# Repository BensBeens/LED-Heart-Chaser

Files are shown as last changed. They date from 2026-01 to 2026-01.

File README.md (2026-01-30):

# LED-Heart-Chaser
Little project that I made as a gift for others. It is a LED chaser circuit that would turn on LEDs in a heart shape when plugged into a USB port. 
It uses a NE555 timer and a 4017 counter for the chaser circuit. It is a 4 layer board (signal layers 1 and 4, VCC layer 3, and GND layer 2)
Hand soldered the SMD components on the PCB when I got the board from Oshpark.com (sourced the components from Mouser.com).

Here is the schematic:


Here is the front of the PCB:



Here is the back of the PCB:



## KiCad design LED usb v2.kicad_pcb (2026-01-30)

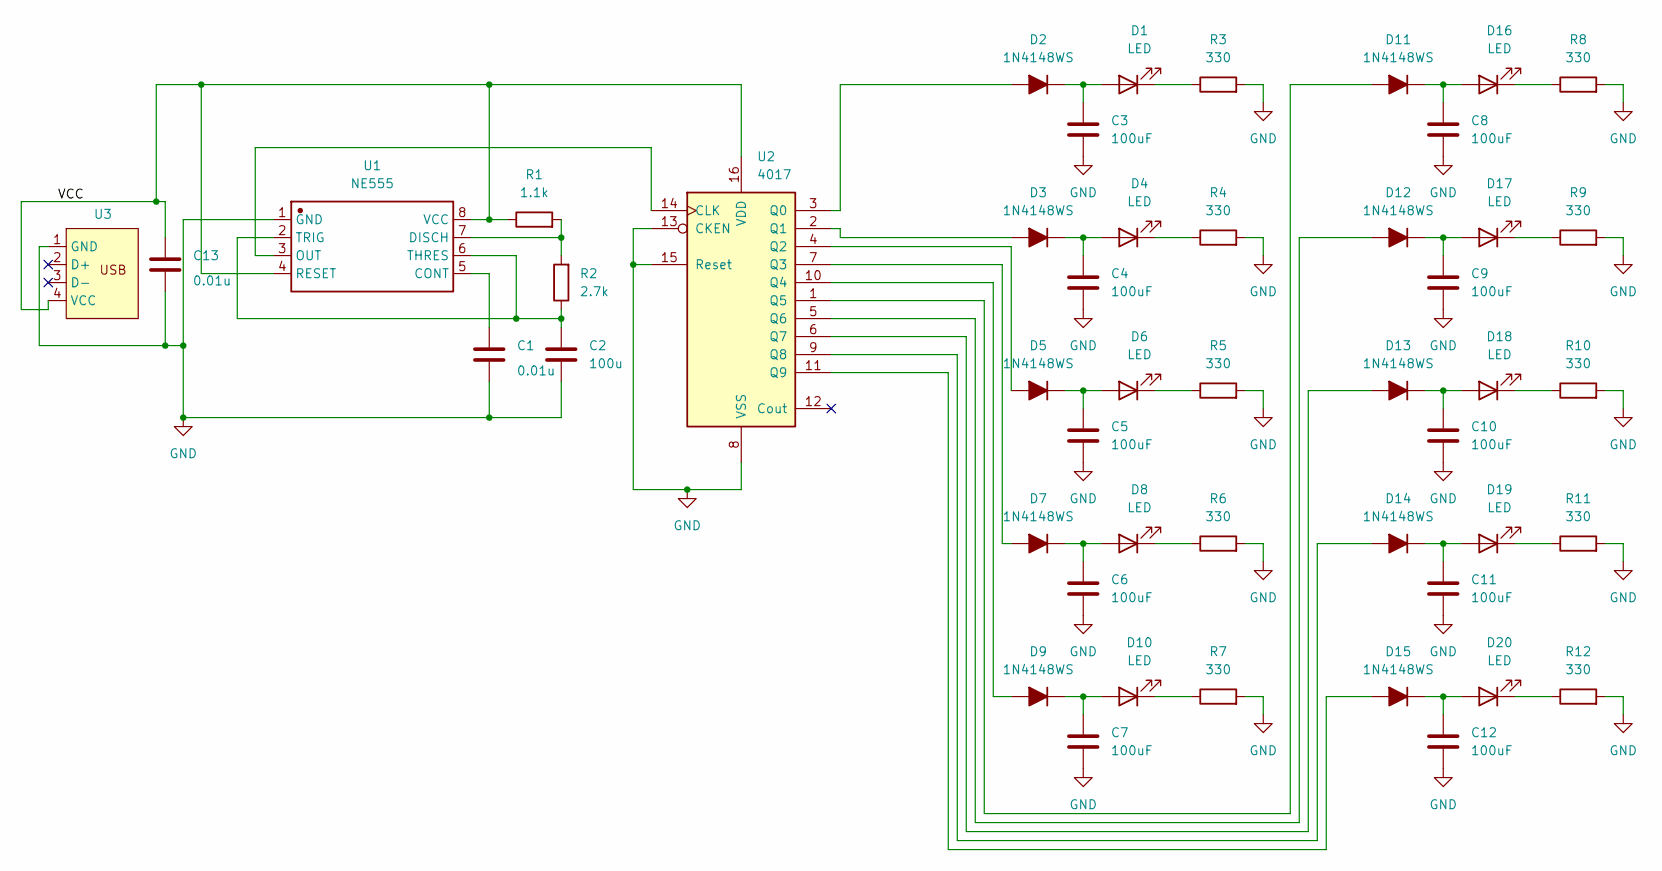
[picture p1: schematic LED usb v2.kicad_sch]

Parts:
C1, C13: 0.01u; 0.01uF(10nF)_C0603
C2: 100u; CAP_SMT_C1206
C3, C4, C5, C6, C7, C8, C9, C10, C11, C12: 100uF; CAP_SMT_C1206
D1, D4, D6, D8, D10, D16, D17, D18, D19, D20: LED; RED_SMD_LED0603-RD
D2, D3, D5, D7, D9, D11, D12, D13, D14, D15: 1N4148WS; Diode_SOD-323_L1.7-W1.3-LS2.7-RD
R1: 1.1k; R0603
R2: 2.7k; R0603
R3, R4, R5, R6, R7, R8, R9, R10, R11, R12: 330; R0603
U1: NE555; NE555DR_SOIC-8_L4.9-W3.9-P1.27-LS6.0-BL; Manufacturer Part NE555
U2: 4017; CD4017BM96G4_SOIC-16_L9.9-W3.9-P1.27-LS6.0-BL
U3: USB_Connector_PCB

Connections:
/VCC: C13.2, R1.1, U1.4 (RESET), U1.8 (VCC), U2.16 (VDD), U3.4 (VCC)
GND: C1.1, C2.1, C3.2, C4.2, C5.2, C6.2, C7.2, C8.2, C9.2, C10.2, C11.2, C12.2, C13.1, R3.2, R4.2, R5.2, R6.2, R7.2, R8.2, R9.2, R10.2, R11.2, R12.2, U1.1 (GND), U2.8 (VSS), U2.13 (CKEN), U2.15 (Reset), U3.1 (GND)
unnamed: C3.1, D1.2 (A), D2.1 (K)
unnamed: D1.1 (K), R3.1
unnamed: D2.2 (A), U2.3 (Q0)
unnamed: D3.2 (A), U2.2 (Q1)
unnamed: C4.1, D3.1 (K), D4.2 (A)
unnamed: D4.1 (K), R4.1
unnamed: D5.2 (A), U2.4 (Q2)
unnamed: C5.1, D5.1 (K), D6.2 (A)
unnamed: D6.1 (K), R5.1
unnamed: D7.2 (A), U2.7 (Q3)
unnamed: C6.1, D7.1 (K), D8.2 (A)
unnamed: D8.1 (K), R6.1
unnamed: D9.2 (A), U2.10 (Q4)
unnamed: C7.1, D9.1 (K), D10.2 (A)
unnamed: D10.1 (K), R7.1
unnamed: D11.2 (A), U2.1 (Q5)
unnamed: C8.1, D11.1 (K), D16.2 (A)
unnamed: D12.2 (A), U2.5 (Q6)
unnamed: C9.1, D12.1 (K), D17.2 (A)
unnamed: D13.2 (A), U2.6 (Q7)
unnamed: C10.1, D13.1 (K), D18.2 (A)
unnamed: D14.2 (A), U2.9 (Q8)
unnamed: C11.1, D14.1 (K), D19.2 (A)
unnamed: D15.2 (A), U2.11 (Q9)
unnamed: C12.1, D15.1 (K), D20.2 (A)
unnamed: D16.1 (K), R8.1
unnamed: D17.1 (K), R9.1
unnamed: D18.1 (K), R10.1
unnamed: D19.1 (K), R11.1
unnamed: D20.1 (K), R12.1
unnamed: C1.2, U1.5 (CONT)
unnamed: R1.2, R2.2, U1.7 (DISCH)
unnamed: U1.3 (OUT), U2.14 (CLK)
unnamed: C2.2, R2.1, U1.2 (TRIG), U1.6 (THRES)

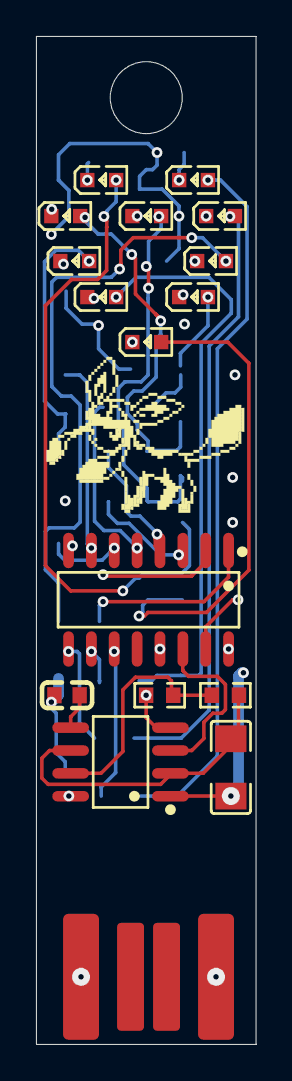
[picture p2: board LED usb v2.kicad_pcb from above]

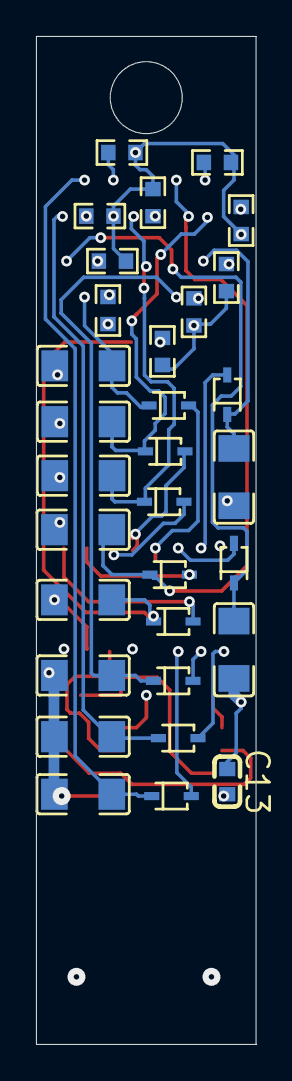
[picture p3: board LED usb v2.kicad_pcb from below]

Board: 4 copper layers, 12.2 x 56.0 mm, 48 parts (31 on the bottom side), 36 nets.
